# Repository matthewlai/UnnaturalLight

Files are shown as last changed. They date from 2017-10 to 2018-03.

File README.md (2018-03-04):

# UnnaturalLight

Lamp with colour temperature setting.

[Introduction](https://dubiouscreations.com/2017/12/02/unnaturallight-part-1-mechanical-optical-design/)

[Mechanical / Optical Design](https://dubiouscreations.com/2017/12/02/unnaturallight-part-1-mechanical-optical-design/)

[Electronics / Firmware Design](https://dubiouscreations.com/2018/01/06/unnaturallight-part-2-electrical-design/)

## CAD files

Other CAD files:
hardware/driver_board/fab/driver_board-F.Paste.dxf
hardware/long_led_board/fab/long_led_board-F.Paste.dxf

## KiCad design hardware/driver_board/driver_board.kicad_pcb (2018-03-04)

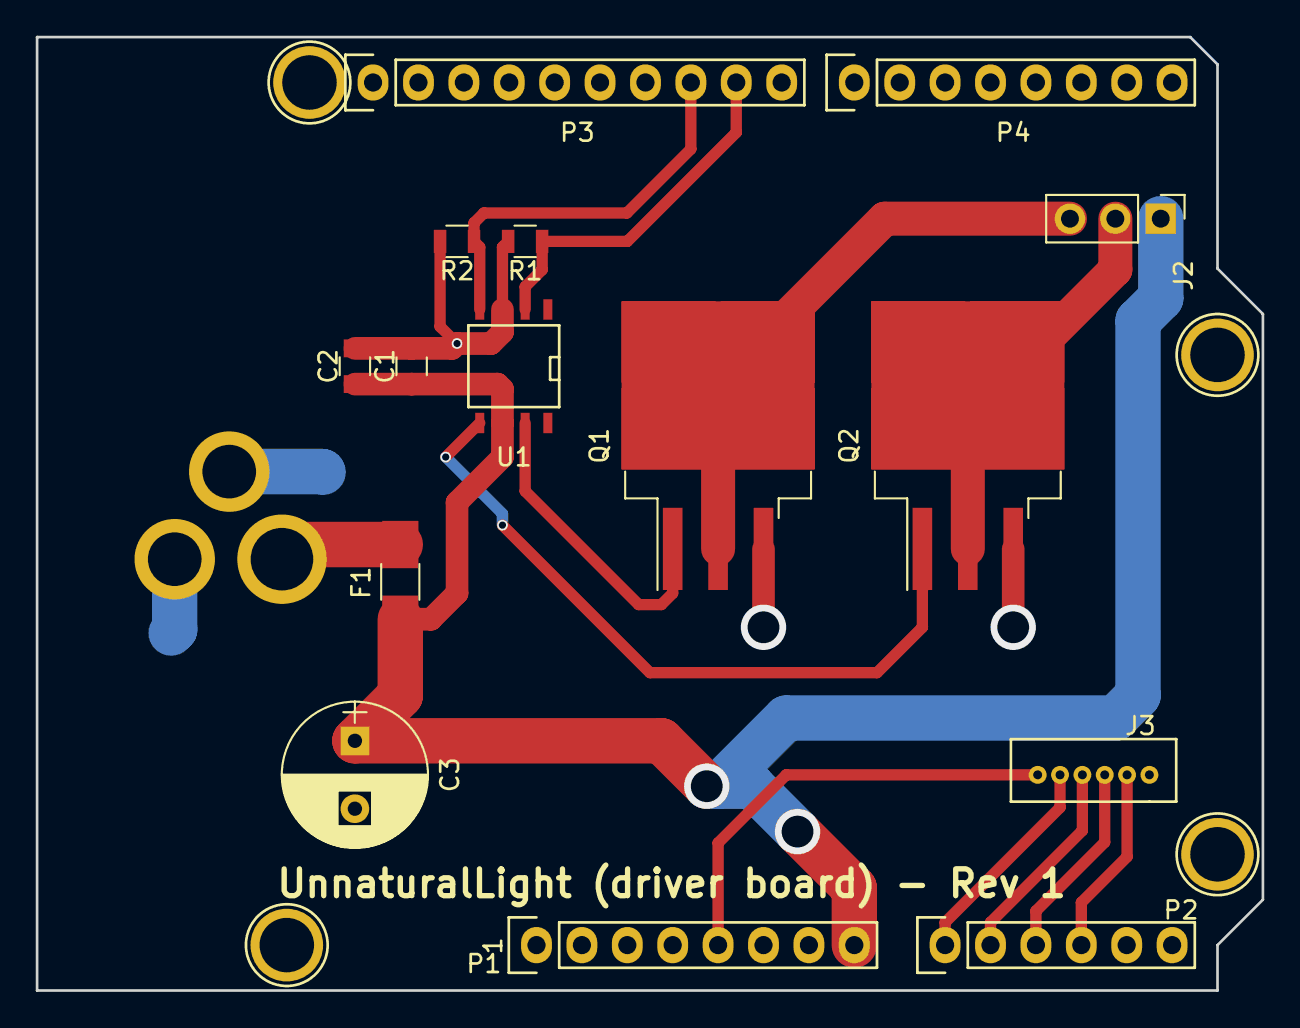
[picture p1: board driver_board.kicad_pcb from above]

Board: 2 copper layers, 68.6 x 53.3 mm, 20 parts (1 on the bottom side), 14 nets.

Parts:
C1: 0.1uF; C_0805
C2: 1uF; C_0805
C3: 220uF; CP_Radial_D8.0mm_P3.80mm
F1: Fuse; Fuse_SMD1206_HandSoldering
J1: BARREL_JACK; Kobiconn_163-179PH-EX
J2: CONN_01X03; Pin_Header_Straight_1x03_Pitch2.54mm
J3: CONN_01X06; Molex_53047_0610
P1: Power; Socket_Strip_Arduino_1x08
P2: Analog; Socket_Strip_Arduino_1x06
P3: Digital; Socket_Strip_Arduino_1x10
P4: Digital; Socket_Strip_Arduino_1x08
P5, P6, P7, P8: CONN_01X01; Arduino_1pin
Q1, Q2: Q_NMOS_GDS; TO-263-3_TabPin2
R1, R2: 10KR; R_0805
U1: MIC4124; SOIC-8-N

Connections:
+5V: J3.6, P1.5
/9(**): P3.9, R1.1, U1.2
/10(**/SS): P3.8, R2.1, U1.4
/A0: J3.5, P2.1
/A1: J3.4, P2.2
/A2: J3.3, P2.3
/A3: J3.2, P2.4
/C_LED: J2.3, Q1.2
/W_LED: J2.2, Q2.2
GND: C1.2, C2.2, C3.2, J1.2, J1.3, J3.1, P1.6, P1.7, P3.4, Q1.3, Q2.3, R1.2, R2.2, U1.3
unnamed: F1.2, J1.1
unnamed: Q1.1, U1.7
unnamed: Q2.1, U1.5
VCC: C1.1, C2.1, C3.1, F1.1, J2.1, P1.8, U1.6

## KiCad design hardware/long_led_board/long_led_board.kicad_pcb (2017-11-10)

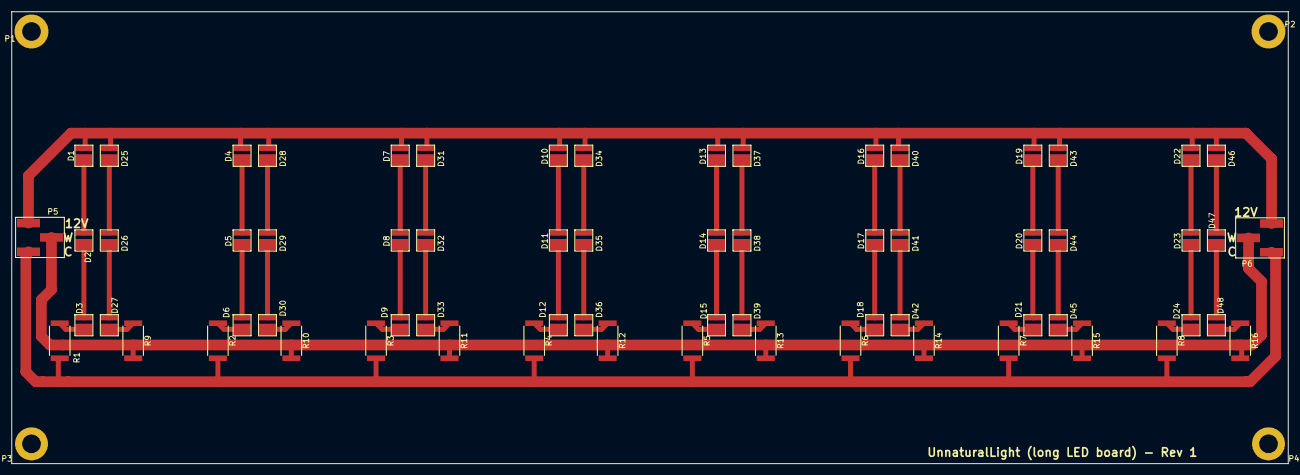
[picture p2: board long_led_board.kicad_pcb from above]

Board: 2 copper layers, 226.0 x 80.0 mm, 70 parts (0 on the bottom side), 51 nets.

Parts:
D1, D2, D3, D4, D5, D6, D7, D8, D9, D10, D11, D12, D13, D14, D15, D16, D17, D18, D19, D20, D21, D22, D23, D24, D25, D26, D27, D28, D29, D30, D31, D32, D33, D34, D35, D36, D37, D38, D39, D40, D41, D42, D43, D44, D45, D46, D47, D48: LED; LED3030
P1, P2, P3, P4: CONN_01X01; M3
P5, P6: CONN_01X03; AMPMODU_MOD_II_3PIN
R1, R2, R3, R4, R5, R6, R7, R8, R9, R10, R11, R12, R13, R14, R15, R16: 8.2R; R_2512

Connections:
+12V: D1.2, D4.2, D7.2, D10.2, D13.2, D16.2, D19.2, D22.2, D25.2, D28.2, D31.2, D34.2, D37.2, D40.2, D43.2, D46.2, P5.3, P6.1
/COOL: P5.1, P6.3, R1.2, R2.2, R3.2, R4.2, R5.2, R6.2, R7.2, R8.2
/WARM: P5.2, P6.2, R9.2, R10.2, R11.2, R12.2, R13.2, R14.2, R15.2, R16.2
unnamed: D1.1, D2.2
unnamed: D2.1, D3.2
unnamed: D3.1, R1.1
unnamed: D4.1, D5.2
unnamed: D5.1, D6.2
unnamed: D6.1, R2.1
unnamed: D7.1, D8.2
unnamed: D8.1, D9.2
unnamed: D9.1, R3.1
unnamed: D10.1, D11.2
unnamed: D11.1, D12.2
unnamed: D12.1, R4.1
unnamed: D13.1, D14.2
unnamed: D14.1, D15.2
unnamed: D15.1, R5.1
unnamed: D16.1, D17.2
unnamed: D17.1, D18.2
unnamed: D18.1, R6.1
unnamed: D19.1, D20.2
unnamed: D20.1, D21.2
unnamed: D21.1, R7.1
unnamed: D22.1, D23.2
unnamed: D23.1, D24.2
unnamed: D24.1, R8.1
unnamed: D25.1, D26.2
unnamed: D26.1, D27.2
unnamed: D27.1, R9.1
unnamed: D28.1, D29.2
unnamed: D29.1, D30.2
unnamed: D30.1, R10.1
unnamed: D31.1, D32.2
unnamed: D32.1, D33.2
unnamed: D33.1, R11.1
unnamed: D34.1, D35.2
unnamed: D35.1, D36.2
unnamed: D36.1, R12.1
unnamed: D37.1, D38.2
unnamed: D38.1, D39.2
unnamed: D39.1, R13.1
unnamed: D40.1, D41.2
unnamed: D41.1, D42.2
unnamed: D42.1, R14.1
unnamed: D43.1, D44.2
unnamed: D44.1, D45.2
unnamed: D45.1, R15.1
unnamed: D46.1, D47.2
unnamed: D47.1, D48.2
unnamed: D48.1, R16.1

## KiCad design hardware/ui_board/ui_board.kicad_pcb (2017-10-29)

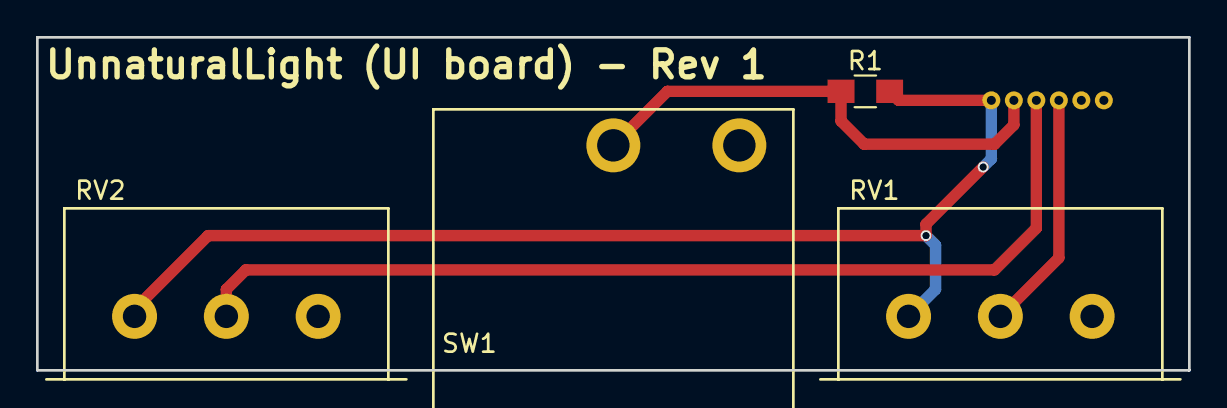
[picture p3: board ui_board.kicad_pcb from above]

Board: 2 copper layers, 64.0 x 18.5 mm, 5 parts (1 on the bottom side), 5 nets.

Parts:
J1: CONN_01X06; Molex_53047_0610
R1: 10KR; R_0805_HandSoldering
RV1, RV2: POT; M_POT
SW1: SW_SPST; CWSA11AAN1S

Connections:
/POT1: J1.4, RV1.2
/POT2: J1.3, RV2.2
/SW: J1.2, R1.1, SW1.1
GND: J1.6, RV1.3, RV2.3, SW1.2
VCC: J1.1, R1.2, RV1.1, RV2.1

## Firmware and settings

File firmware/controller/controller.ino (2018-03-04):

/*
 * This file is part of the UnnaturalLight project.
 *
 * Copyright (C) 2018 Matthew Lai <m@matthewlai.ca>
 *
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
 * You should have received a copy of the GNU General Public License
 * along with this program.  If not, see <http://www.gnu.org/licenses/>.
 */

const int kHysteresis = 2;
const int kHysteresisStepSize = 1; // per control period
const int kControlPeriodMs = 3;

const int kPower1Pin = 9;
const int kPower2Pin = 10;

const int kSwitchADCChannel = 0;
const int kPowerADCChannel = 1;
const int kColourADCChannel = 2;

// We reduce potentiometer range by this much on both ends because
// some shitty potentiometers can't go all the way to 0 and Vcc.
const int kSaturation = 20;

// These are power settings after hyesteresis, but before filtering
unsigned int power_1_hys = 0;
unsigned int power_2_hys = 0;

// These are power settings after filtering (and are the PWM settings)
unsigned int power_1_pwm = 0;
unsigned int power_2_pwm = 0;

// true = up, false = down
bool power_1_dir = true;
bool power_2_dir = true;

// Maps [kSaturation, 255 - kSaturation] to [0, 255].
unsigned int saturate(unsigned int x) {
  if (x < kSaturation) {
    return 0;
  } else if (x > (255 - kSaturation)) {
    return 255;
  } else {
    long range = 255 - (2 * kSaturation);
    return (x - kSaturation) * 255 / range;
  }
}

// if abs(new_x - old_x) >= kHysteresis, we return new_x
// otherwise, we return new_x if new_x - old_x is in the right direction
// otherwise, we return old_x
// dir is updated depending on the sign of new_x - old_x
unsigned int apply_hysteresis(unsigned int old_x, unsigned int new_x, bool& dir) {
  bool new_dir = (new_x > old_x);
  if (abs(new_x - old_x) > kHysteresis) {
    dir = new_dir;
    return new_x;
  } else if (new_dir == dir) {
    return new_x;
  } else {
    return old_x;
  }
}

unsigned int apply_filter(unsigned int old_x, unsigned int new_x) {
  if (new_x < old_x) {
    return old_x - min(kHysteresisStepSize, old_x - new_x);
  } else if (new_x > old_x) {
    return old_x + min(kHysteresisStepSize, new_x - old_x);
  } else {
    return old_x;
  }
}

void setup() {
  // Pin 13 is connected to the annoying 'L' LED. Turn it off.
  pinMode(13, OUTPUT);
  digitalWrite(13, LOW);

  pinMode(kPower1Pin, OUTPUT);
  pinMode(kPower2Pin, OUTPUT);

  analogWrite(kPower1Pin, 0);
  analogWrite(kPower2Pin, 0);

  // We are using pins 9, 10 on timer1.
  // Arduino defaults to ~488Hz, which is very low. It creates flicker in photography,
  // and produces inductor whine in power adapter.
  // We have dedicated gate drivers, so let's go much faster!
  // This sets it to 31.25kHz (the fastest atmega328p can do)
  TCCR1B &= 0b11111001;  

  Serial.begin(115200);
}

void loop() {
  bool  = analogRead(kSwitchADCChannel) < 512;
  unsigned int power_setting = saturate(255 - (analogRead(kPowerADCChannel) / 4));
  unsigned int colour_setting = saturate(255 - (analogRead(kColourADCChannel) / 4));

  // Switch override
  if (!switch_setting) {
    power_setting = 0;
  }

  unsigned int new_power_1 = power_setting * colour_setting / 255;
  unsigned int new_power_2 = power_setting - new_power_1;

  // Apply hysteresis
  power_1_hys = apply_hysteresis(power_1_hys, new_power_1, power_1_dir);
  power_2_hys = apply_hysteresis(power_2_hys, new_power_2, power_2_dir);

  // Apply filter
  power_1_pwm = apply_filter(power_1_pwm, power_1_hys);
  power_2_pwm = apply_filter(power_2_pwm, power_2_hys);
  
  analogWrite(kPower1Pin, power_1_pwm);
  analogWrite(kPower2Pin, power_2_pwm);
  
  delay(kControlPeriodMs);
}

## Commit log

2016-12-19 Added hardware
    [WifiLED-B.Cu.gbr, WifiLED-B.Mask.gbr, WifiLED-B.SilkS.gbr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]
2017-02-04 Improved flashing script to tell the bootloader we have 3.3V supply (and flash faster)
2017-02-04 Improved cdcacm and added other support files
    [WifiLED-B.Cu.gbr]
2017-02-04 Added hardware design for WifiLED
    [WifiLED.kicad_pcb, WifiLED.sch]
2017-10-11 Removed libopencm3 and software
    [WifiLED.kicad_pcb, WifiLED.sch]
2017-10-11 Cleaned up for git import
    [WifiLED-B.Cu.gbr, WifiLED-B.Mask.gbr, WifiLED-B.SilkS.gbr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]
2017-10-11 Initial commit of driver and UI boards
    [driver_board.kicad_pcb, driver_board.sch, ui_board.kicad_pcb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]
2017-10-15 Finished rev1 PCBs
    [driver_board.kicad_pcb, driver_board.sch, ui_board.kicad_pcb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]
2017-10-29 Added fab files
    [WifiLED-B.Cu.gbr, WifiLED-B.Mask.gbr, WifiLED-B.SilkS.gbr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]
2017-11-05 Changed LED board connectors to SMD
    [led_board.kicad_pcb, led_board.sch]
2017-11-10 Added long LED board design
    [long_led_board.kicad_pcb, long_led_board.sch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]
2017-11-23 Added paste dxfs
    [driver_board-F.Paste.dxf, driver_board.kicad_pcb, long_led_board-F.Paste.dxf]
2018-03-04 Added arduino firmware

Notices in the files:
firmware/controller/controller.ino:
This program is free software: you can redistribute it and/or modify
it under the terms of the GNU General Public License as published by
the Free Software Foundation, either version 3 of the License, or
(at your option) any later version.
